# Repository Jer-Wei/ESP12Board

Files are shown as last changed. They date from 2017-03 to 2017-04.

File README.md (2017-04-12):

# ESP12Board
KiCad PCB design for ESP12 projects board.
This becomes my personal 'universal' breakout board for the ESP12.

- As small as possible
- Solderable by beginners
- Cheap components
- Feature rich

Get the latest release from: https://github.com/Thijxx/ESP12Board/releases

*I sent v2 to the manufacturer*

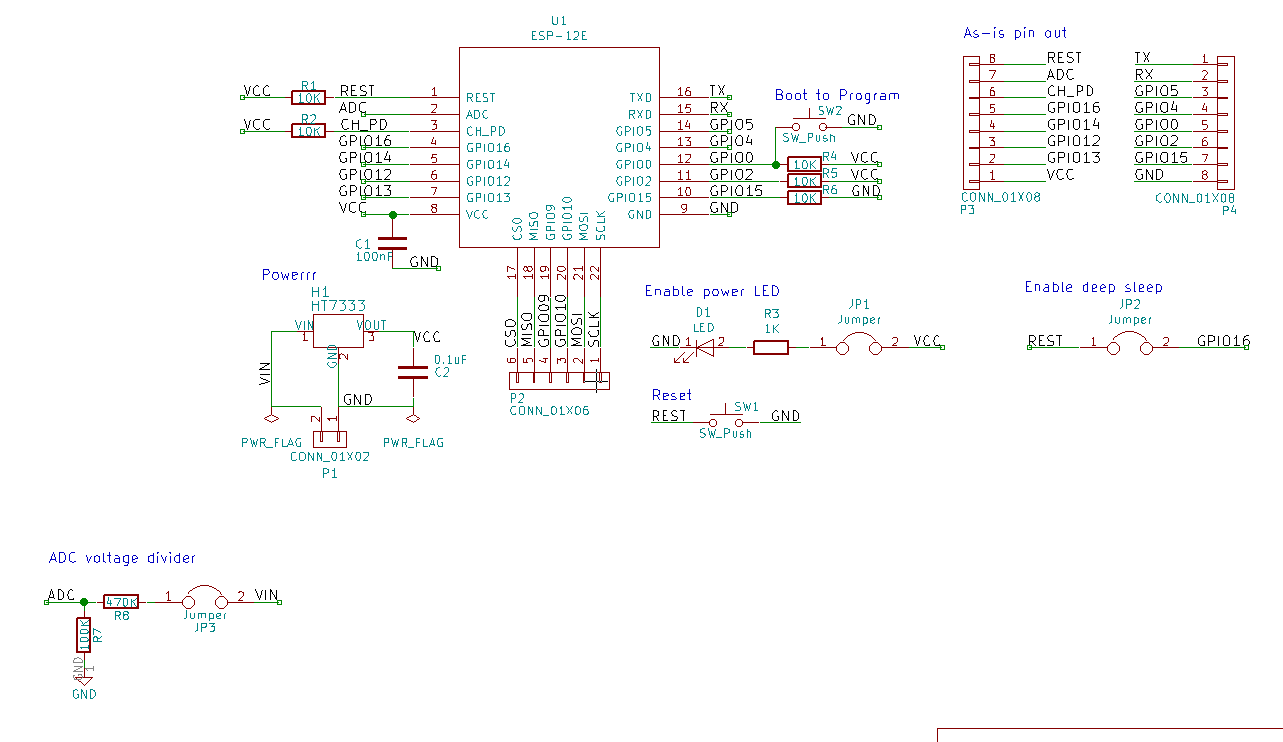
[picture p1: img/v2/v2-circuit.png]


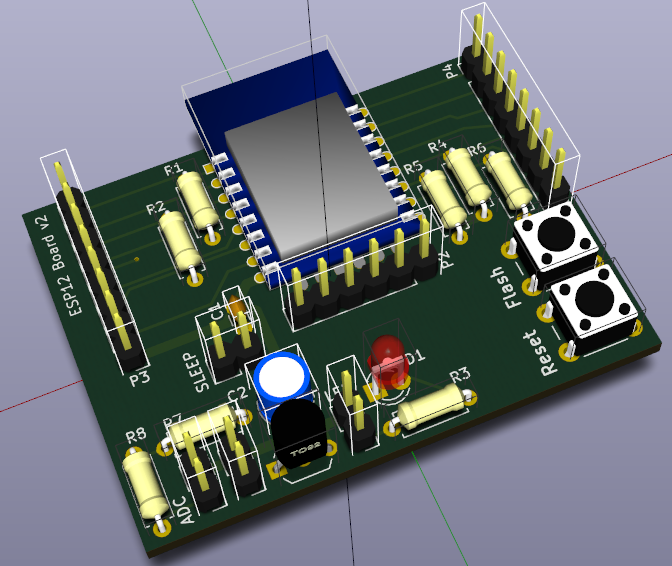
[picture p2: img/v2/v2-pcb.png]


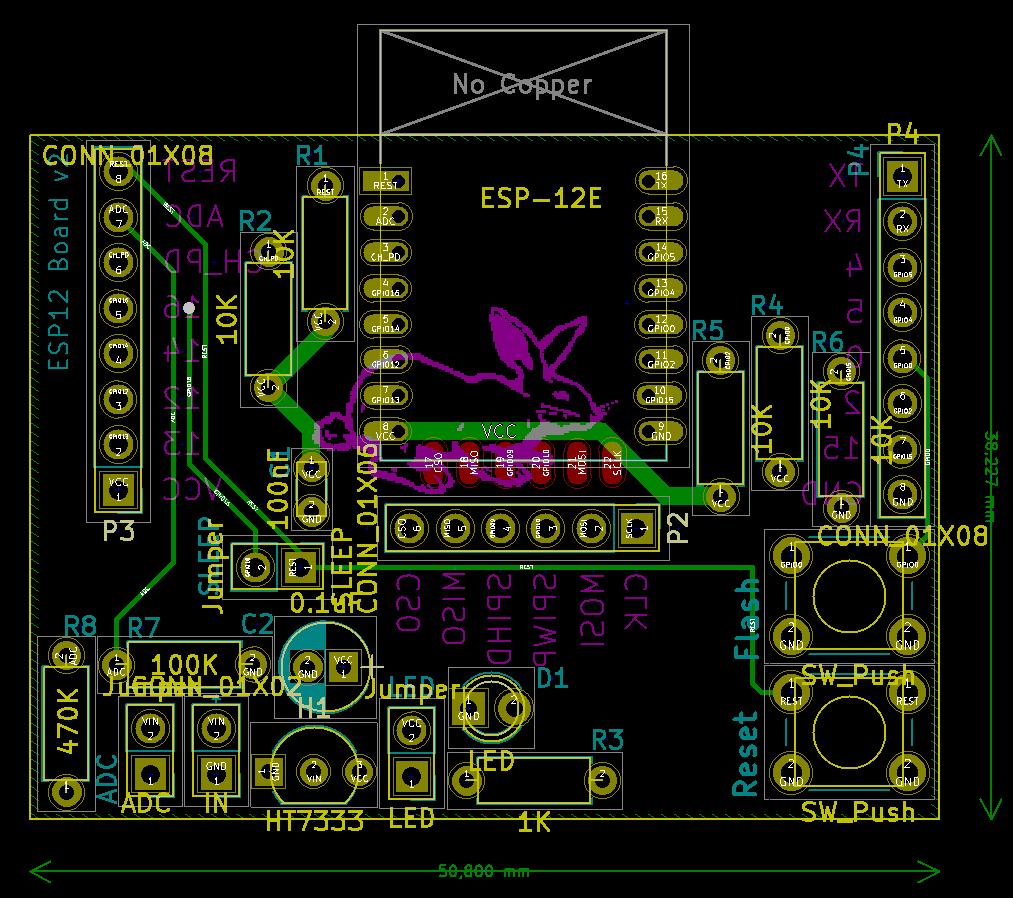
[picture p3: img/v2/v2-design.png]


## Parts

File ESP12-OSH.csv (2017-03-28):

Reference | Value | Footprint | Datasheet
R6 | 10K | Resistors_THT:R_Axial_DIN0207_L6.3mm_D2.5mm_P7.62mm_Horizontal
R2 | 10K | Resistors_THT:R_Axial_DIN0207_L6.3mm_D2.5mm_P7.62mm_Horizontal
D1 | LED | LEDs:LED_D3.0mm
R3 | 1K | Resistors_THT:R_Axial_DIN0207_L6.3mm_D2.5mm_P7.62mm_Horizontal
P3 | CONN_01X08 | Pin_Headers:Pin_Header_Straight_1x08_Pitch2.54mm
P2 | CONN_01X06 | Pin_Headers:Pin_Header_Straight_1x06_Pitch2.54mm
JP1 | Jumper | Pin_Headers:Pin_Header_Straight_1x02_Pitch2.54mm
R1 | 10K | Resistors_THT:R_Axial_DIN0207_L6.3mm_D2.5mm_P7.62mm_Horizontal
P4 | CONN_01X08 | Pin_Headers:Pin_Header_Straight_1x08_Pitch2.54mm
P1 | CONN_01X02 | Pin_Headers:Pin_Header_Straight_1x02_Pitch2.54mm
C2 | 0.1uF | Capacitors_THT:CP_Radial_D5.0mm_P2.00mm
U1 | ESP-12E | ESP8266:ESP-12E
C1 | 100nF | Capacitors_THT:C_Disc_D3.0mm_W1.6mm_P2.50mm
H1 | HT7333 | TO_SOT_Packages_THT:TO-92_Inline_Narrow_Oval
SW2 | SW_Push | Buttons_Switches_THT:SW_PUSH_6mm
SW1 | SW_Push | Buttons_Switches_THT:SW_PUSH_6mm
R5 | 10K | Resistors_THT:R_Axial_DIN0207_L6.3mm_D2.5mm_P7.62mm_Horizontal
R4 | 10K | Resistors_THT:R_Axial_DIN0207_L6.3mm_D2.5mm_P7.62mm_Horizontal
JP2 | Jumper | Pin_Headers:Pin_Header_Straight_1x02_Pitch2.54mm

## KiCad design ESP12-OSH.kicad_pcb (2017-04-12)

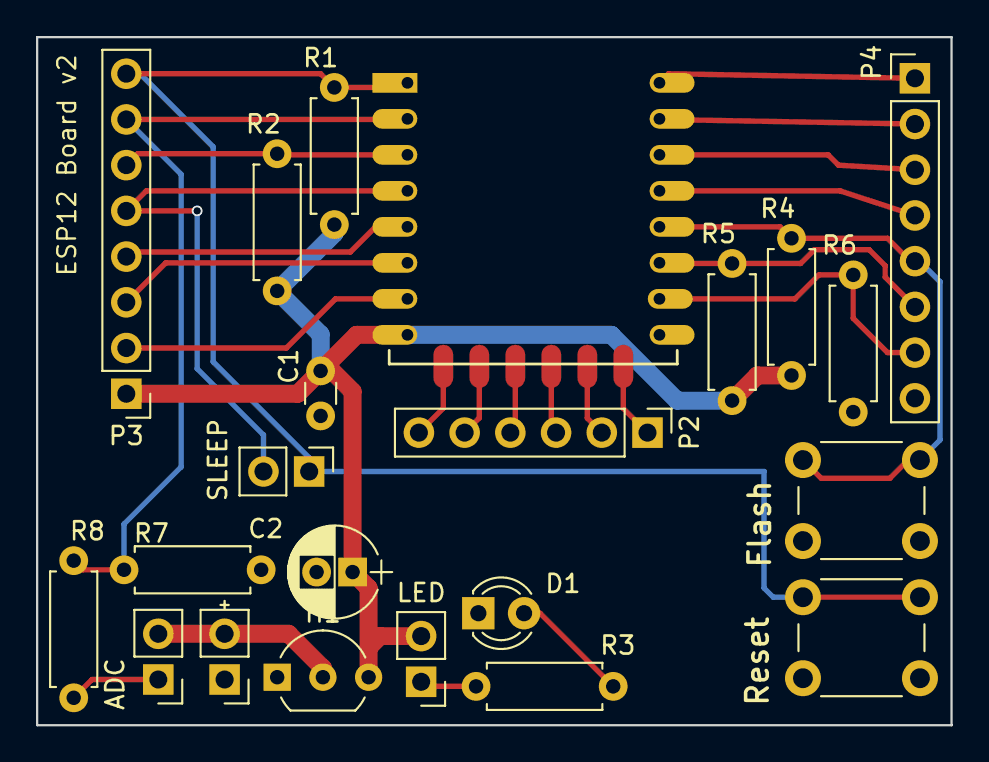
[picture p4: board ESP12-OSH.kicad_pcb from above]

Board: 2 copper layers, 50.8 x 38.2 mm, 23 parts (1 on the bottom side), 26 nets.

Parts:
ADC: Jumper; Pin_Header_Straight_1x02_Pitch2.54mm
C1: 100nF; C_Disc_D3.0mm_W1.6mm_P2.50mm
C2: 0.1uF; CP_Radial_D5.0mm_P2.00mm
D1: LED; LED_D3.0mm
H1: HT7333; TO-92_Inline_Wide
IN: CONN_01X02; Pin_Header_Straight_1x02_Pitch2.54mm
LED: Jumper; Pin_Header_Straight_1x02_Pitch2.54mm
LOGO: newlogo
P2: CONN_01X06; Pin_Header_Straight_1x06_Pitch2.54mm
P3, P4: CONN_01X08; Pin_Header_Straight_1x08_Pitch2.54mm
R1, R2, R4, R5, R6: 10K; R_Axial_DIN0207_L6.3mm_D2.5mm_P7.62mm_Horizontal
R3: 1K; R_Axial_DIN0207_L6.3mm_D2.5mm_P7.62mm_Horizontal
R7: 100K; R_Axial_DIN0207_L6.3mm_D2.5mm_P7.62mm_Horizontal
R8: 470K; R_Axial_DIN0207_L6.3mm_D2.5mm_P7.62mm_Horizontal
SLEEP: Jumper; Pin_Header_Straight_1x02_Pitch2.54mm
SW1, SW2: SW_Push; SW_PUSH_6mm
U1: ESP-12E

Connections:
/ADC: P3.7, R7.1, R8.2, U1.2
/CH_PD: P3.6, R2.1, U1.3
/CSO: P2.6, U1.17
/GPIO0: P4.5, R4.2, SW2.1, U1.12
/GPIO2: P4.6, R5.2, U1.11
/GPIO4: P4.4, U1.13
/GPIO5: P4.3, U1.14
/GPIO09: P2.4, U1.19
/GPIO10: P2.3, U1.20
/GPIO12: P3.3, U1.6
/GPIO13: P3.2, U1.7
/GPIO14: P3.4, U1.5
/GPIO15: P4.7, R6.2, U1.10
/GPIO16: P3.5, SLEEP.2, U1.4
/MISO: P2.5, U1.18
/MOSI: P2.2, U1.21
/REST: P3.8, R1.1, SLEEP.1, SW1.1, U1.1
/RX: P4.2, U1.15
/SCLK: P2.1, U1.22
/TX: P4.1, U1.16
/VCC: C1.1, C2.1, H1.3, LED.2, P3.1, R1.2, R2.2, R4.1, R5.1, U1.8
/VIN: ADC.2, H1.2, IN.2
GND: C1.2, C2.2, D1.1, H1.1, IN.1, P4.8, R6.1, R7.2, SW1.2, SW2.2, U1.9
unnamed: D1.2, R3.2
unnamed: LED.1, R3.1
unnamed: ADC.1, R8.1

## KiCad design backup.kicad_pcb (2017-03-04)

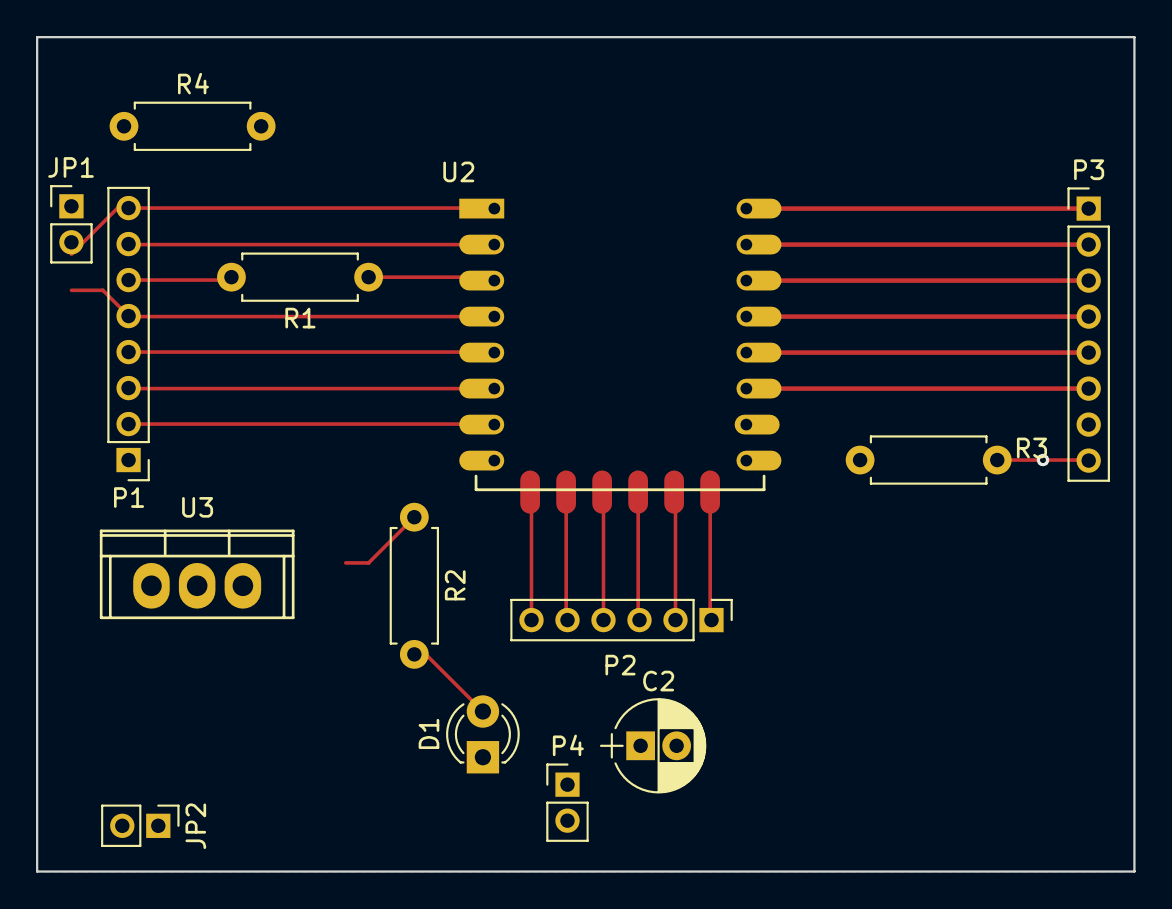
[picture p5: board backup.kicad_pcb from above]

Board: 2 copper layers, 61.0 x 46.4 mm, 14 parts (0 on the bottom side), 25 nets.

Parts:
C2: 0.1uF; CP_Radial_D5.0mm_P2.00mm
D1: LED; LED_D3.0mm
JP1, JP2: Jumper; Pin_Header_Straight_1x02_Pitch2.00mm
P1, P3: CONN_01X08; Pin_Header_Straight_1x08_Pitch2.00mm
P2: CONN_01X06; Pin_Header_Straight_1x06_Pitch2.00mm
P4: CONN_01X02; Pin_Header_Straight_1x02_Pitch2.00mm
R1: 100; R_Axial_DIN0207_L6.3mm_D2.5mm_P7.62mm_Horizontal
R2, R3: 1K; R_Axial_DIN0207_L6.3mm_D2.5mm_P7.62mm_Horizontal
R4: 10K; R_Axial_DIN0207_L6.3mm_D2.5mm_P7.62mm_Horizontal
U2: ESP-12E
U3: SPX2920U-3.3; TO-220

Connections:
/GND: C2.1, D1.1, P3.7, P3.8, P4.1, R3.1, U2.9, U3.2
/RX: P3.2, U2.15
/TX: P3.1, U2.16
/VCC: C2.2, JP2.2, P1.1, P1.6, R1.2, R4.2, U2.8, U3.3
unnamed: D1.2, R2.2
unnamed: JP1.1, P1.8, R4.1, U2.1
unnamed: JP1.2, P1.5, U2.4
unnamed: JP2.1, R2.1
unnamed: P1.2, U2.7
unnamed: P1.3, U2.6
unnamed: P1.4, U2.5
unnamed: P1.7, U2.2
unnamed: P2.1, U2.22
unnamed: P2.2, U2.21
unnamed: P2.3, U2.20
unnamed: P2.4, U2.19
unnamed: P2.5, U2.18
unnamed: P2.6, U2.17
unnamed: P3.3, U2.14
unnamed: P3.4, U2.13
unnamed: P3.5, U2.12
unnamed: P3.6, U2.11
unnamed: P4.2, U3.1
unnamed: R1.1, U2.3
unnamed: R3.2, U2.10

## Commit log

2017-02-27 first version of ESP12 board
    [esp12breakout.kicad_pcb, esp12breakout.sch]
2017-02-27 power input en vias
    [esp12breakout.kicad_pcb, esp12breakout.sch]
2017-03-04 reworked, based on OSH Park template for KiCad
    [ESP12-OSH.kicad_pcb, ESP12-OSH.sch, backup.kicad_pcb]
2017-03-04 headers with 2.54mm spacing
    [ESP12-OSH.kicad_pcb, ESP12-OSH.sch]
2017-03-05 commit before SO question
    [ESP12-OSH.kicad_pcb]
2017-03-05 extra small cap, moved large cap, removed front zone VCC, removed vias, moved parts around, added mounting holes
    [ESP12-OSH.kicad_pcb, ESP12-OSH.sch]
2017-03-25 Update README.md
    added power consumption measurements
2017-03-28 switches for control and start with voltage divider for battery capacity management
    [ESP12-OSH.sch]
2017-03-28 setup for version 2
    [ESP12-OSH.csv, klein.kicad_pcb]
2017-03-28 footprint fix for HT7333
2017-03-29 version 2 in the works!
    [ESP12-OSH.kicad_pcb, ESP12-OSH.sch, klein.kicad_pcb]
2017-04-02 thicker traces, antenna outside of pcb, shorter traces, removed custom HT7333 footprint
    [ESP12-OSH.kicad_pcb, ESP12-OSH.sch]
2017-04-04 text on back and front silk improved
    [ESP12-OSH.kicad_pcb]
2017-04-12 mini tweaks before sending the design to the manufacturer
    [ESP12-OSH.kicad_pcb]
